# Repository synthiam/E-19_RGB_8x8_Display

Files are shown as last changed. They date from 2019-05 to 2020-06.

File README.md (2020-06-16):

# E-19 RGB 8x8 Display

**Project Status:** Ready to manufacture

If you are new to GitHub and would like to create a derivative of this project, please have a look at GitHub instructions to [fork a repo](https://help.github.com/en/articles/fork-a-repo)

## Description

Out of our passion to solve the issue of time waste in the robot creation process, ARC was born. The ARC software platform reduces the time it takes to get from idea to implementation. Since 2011 we have been listening to the challenges robot builders encounter and continue to provide them with an ever expanding toolbox of solutions. Join us on this journey!

We didn't stop at the software, we also made time saving hardware solutions. This RGB Matrix display reference design is one of them. It has 64 (8x8 matrix) Full color LEDs. Each LED can be individually controlled by EZ-builder to form messages, pictures, games, and more! A unique feature of this display is that it is a smaller form factor (48x48mm) than common RGB matrix dispalys (60x60mm). We want to share these files with you so you can create your own version for your community and customers to enjoy!

**Features:**
- I2C communication
- Adjustable I2C address for chaining multiple displays
- PIC programming header
- 5V tolerant I/O pins
- Address displayed on boot
- ARC skill available
- Small form factor RGB display
- Vibrant Green color, better than majority of matrix displays 
- Voltage requirement: 3.2-3.4VDC (3.3V Typical)
- Current draw: All LEDs off - 6.6mA, All Blue - 86mA, All Green - 106mA, All Red - 154mA, All White - 273mA
- Dimensions: 48(W) x 48(L) x 15.6(H) (mm)
- Weight: 32g

**Major components:** 
- HS-19088BSRND-GG RGB 8x8 LED Matrix
- PIC16F1937 PIC microcontroller (custom firmware provided)

**Manufacturing notes:** 
1. Supplier: programs custom firmware into the PIC16F1937 at their facility before sending to manufacturer
2. Manufacturer: Single side placement and soldering of SMT components
3. Manufacturer: Dual Side soldering of THT components

## Contents

[**Documentation:**](https://github.com/synthiam/E-19_RGB_8x8_Display/tree/master/E-19%20Documentation) Schematic PDF, Datasheet PDF, BOM, Assembly Notes, Test Procedures

[**Hardware:**](https://github.com/synthiam/E-19_RGB_8x8_Display/tree/master/E-19%20Hardware) Altium PCB design File, Altium SCH Design File, Gerbers

[**Firmware:**](https://github.com/synthiam/E-19_RGB_8x8_Display/tree/master/E-19%20Firmware) Code, Compiled Hex

*Altium Libraries are also available <a href="https://github.com/synthiam/Synthiam_Altium_Librairies">here</a>*

## Photos

<p align="left">


</p>

## Roll Out Video

This Roll-out Video includes:

1. Feature set 
2. Hook-up guide 
3. Using ARC Skill
4. Schematic overview
5. Bill of Materials (BOM) overview
6. Custom firmware location
7. Assembly instructions 

Link: https://youtu.be/Iwhcii0WCHs



## ARC Skill

The ARC skill for this reference design is very easy to use! Simply add an animation frame, click on the pixels, choose the color, and repeat! Activate the animations with the click of a mouse button or with code. 

Link: https://synthiam.com/Software/Manual/RGB-8x8-Animator-16173

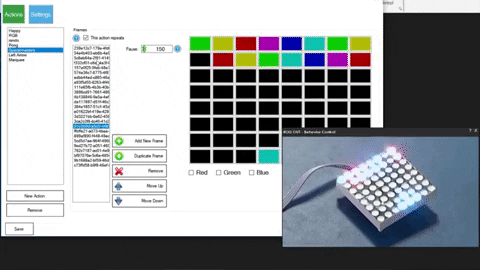
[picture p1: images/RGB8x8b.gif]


## Contact

For profit use of these files requires written consent. Contact partners@synthiam.com. For everyone else, party on!

Synthiam Website: https://synthiam.com

## License

This project is released under the following licenses:

**Hardware:** Creative Commons Plus Attribution-NonCommercial 4.0 International (CC+ BY-NC 4.0)

**Firmware:** Apache 2.0 + “Commons Clause” License Condition v1.0

Please see [LICENSE.md](https://github.com/synthiam/E-19_RGB_8x8_Display/blob/master/LICENSE.md) for license details.



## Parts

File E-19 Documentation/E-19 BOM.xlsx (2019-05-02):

Qty | Description | Manufacturer Part No. | Alternative | Designator | Custom Information | Link
E-19 RGB 8x8 Display
1 | 2 layer, Blue soldermask, White silkscreen, ENIG | RGB 8x8 Display Board |  | PCB
1 | 2 layer, Blue soldermask, White silkscreen, ENIG | EZ-clip Board |  | PCB2
1 | Microchip Microcontroller | PIC16F1937-I/PT |  | U1 | Needs Eyes Firmware programmed onto chip before manufacturing | https://www.digikey.ca/products/en?keywords=PIC16F1937-I%2FPT
1 | 4-pin 2mm pitch JST-PH SMD connector | S4B-PH-SM4-TB(LF)(SN) |  | P2 |  | https://www.digikey.ca/products/en?keywords=%09455-1706-ND
8 | 530mA 30V P-Channel MOSFET SOT23 low gate capacitance (76pF) | DMP31D0U-7 |  | Q1, Q2 |  | http://www.digikey.ca/product-detail/en/S4B-PH-SM4-TB(LF)(SN)/455-1751-1-ND/926848
1 | 0.1uF 16V 0805 Ceramic Capacitor | CL21F104ZBCNNNC | C0805C104K5RAC | C3
10 | 4.7Kohm 0805 Resistor | RR1220P-472-D |  | R2, R3, R4, R5, R6, R7, R8, R9, R10, R11
1 | 40-pin Black Male 0.1” pitch header | FIT0084-B | 00834 | P5, P6 | This header needs to be broken down into 2 x 4-pin | http://www.4uconnector.com/online/SearchPro.asp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
1 | Common Anode 1.9" 8x8 RGB LED display white diffused lens, black foreground | HS-19088BSRND-GG |  | P3, P4 |  | https://www.alibaba.com/product-detail/8x8-RGB-LED-Matrix-Display-48x48x9mm_60031953303.html
2 | 10mm (W) x 10mm (L) x 1mm (H) Doubled sided foam tape |  |  |  | Need to cut to length | http://www.aliexpress.com/item/1mm-thick-10mm-width-3M-Automotive-Acrylic-Foam-Double-Sided-Adhesive-Tape-x-2-Rolls/32495049028.html

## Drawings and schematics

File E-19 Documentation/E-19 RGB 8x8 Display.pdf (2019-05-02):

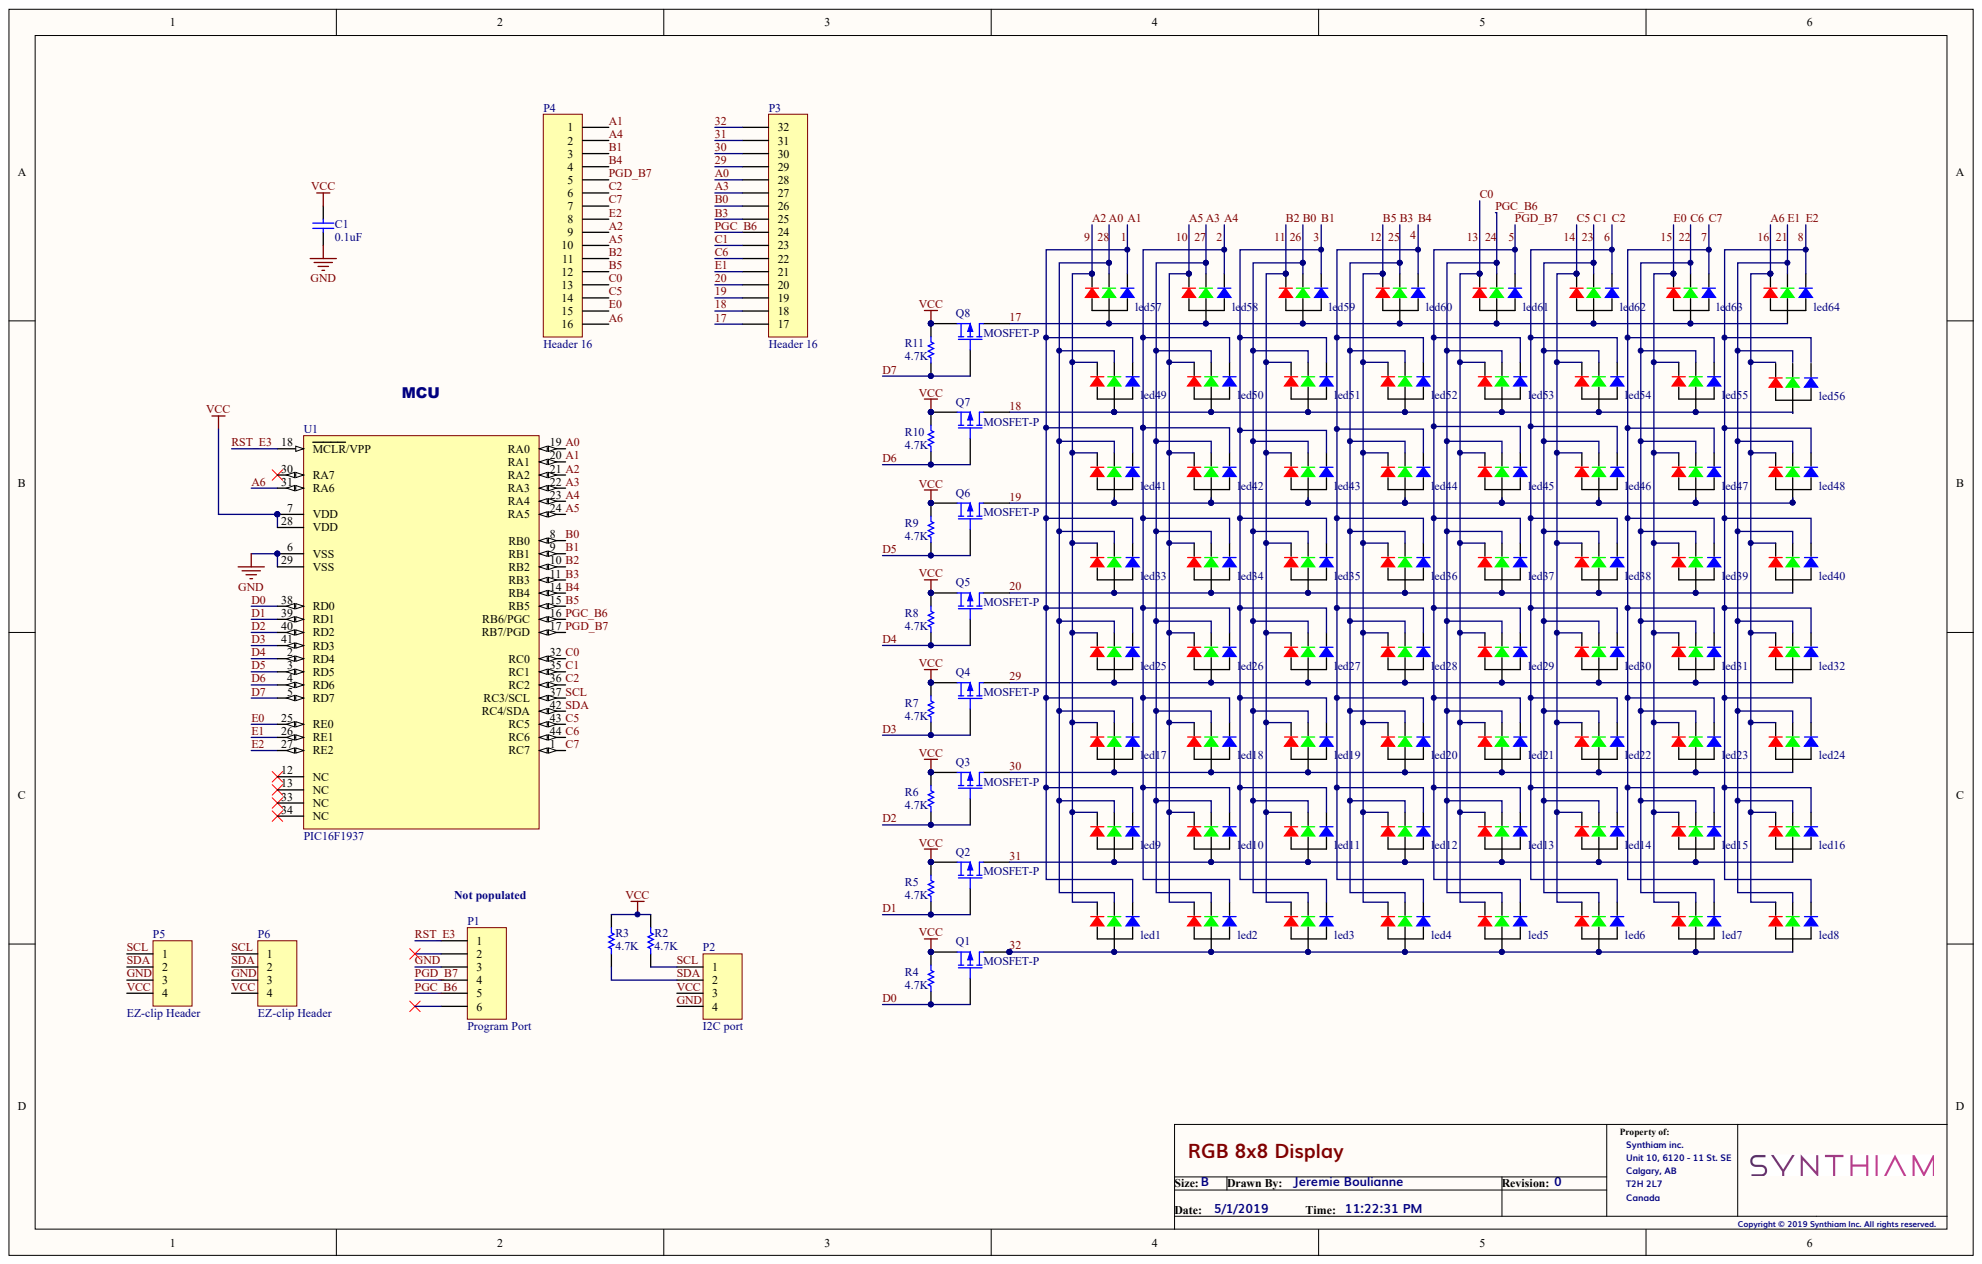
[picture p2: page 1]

RGB 8x8 Display | Property of: Synthiam inc. Unit 10, 6120 - 11 St. SE Calgary, AB T2H 2L7 Canada

B Size: | Jeremie Boulianne Drawn By: | 0 Revision:
5/1/2019 11:22:31 PM Date: Time:

Copyright © 2019 Synthiam Inc. All rights reserved.

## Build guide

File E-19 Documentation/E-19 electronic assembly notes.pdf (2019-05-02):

# Assembly Instructions

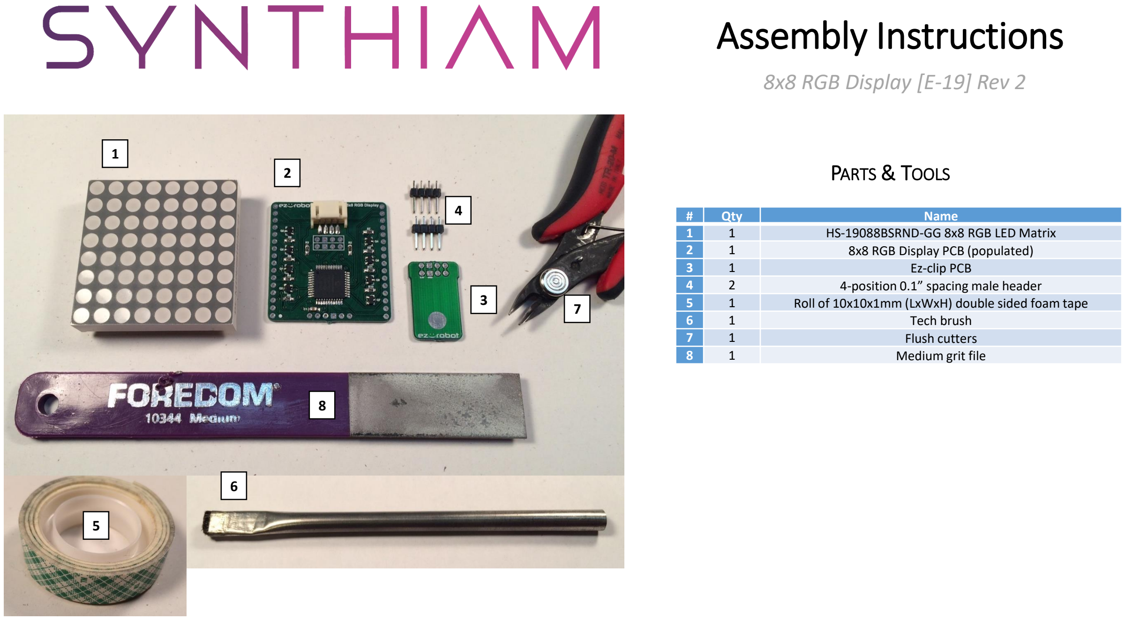
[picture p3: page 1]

# | Qty | Name

1 | 1 | HS-19088BSRND-GG 8x8 RGB LED Matrix
2 | 1 | 8x8 RGB Display PCB (populated)
3 | 1 | Ez-clip PCB
4 | 2 | 4-position 0.1” spacing male header
5 | 1 | Roll of 10x10x1mm (LxWxH) double sided foam tape
6 | 1 | Tech brush
7 | 1 | Flush cutters
8 | 1 | Medium grit file

8x8 RGB Display [E-19] Rev 2

PARTS & TOOLS

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
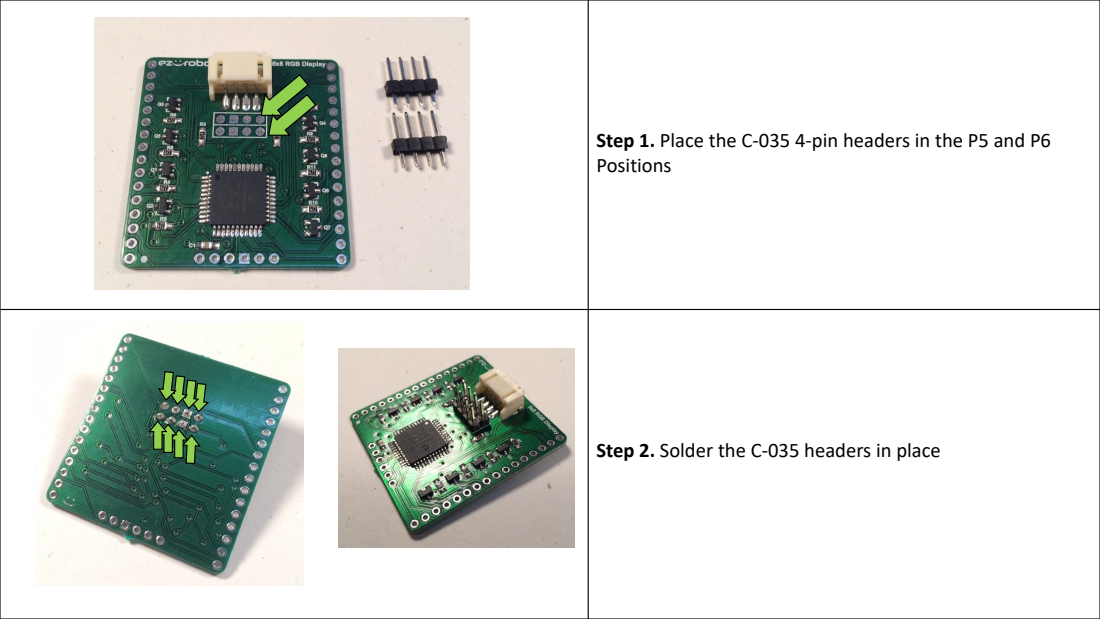
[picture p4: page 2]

Step 1. Place the C-035 4-pin headers in the P5 and P6
Positions

Step 2. Solder the C-035 headers in place

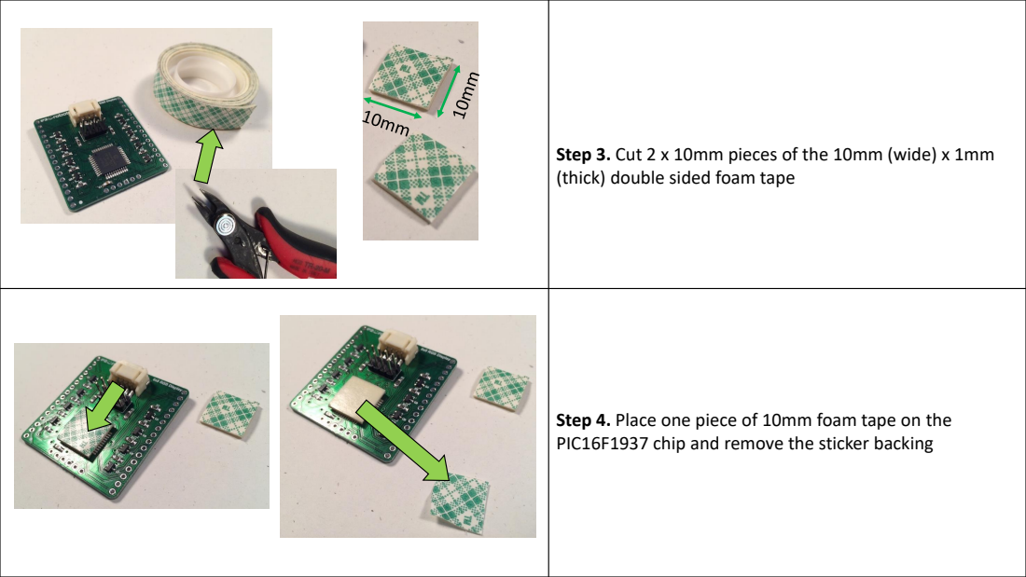
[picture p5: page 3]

Step 3. Cut 2 x 10mm pieces of the 10mm (wide) x 1mm
(thick) double sided foam tape

Step 4. Place one piece of 10mm foam tape on the
PIC16F1937 chip and remove the sticker backing

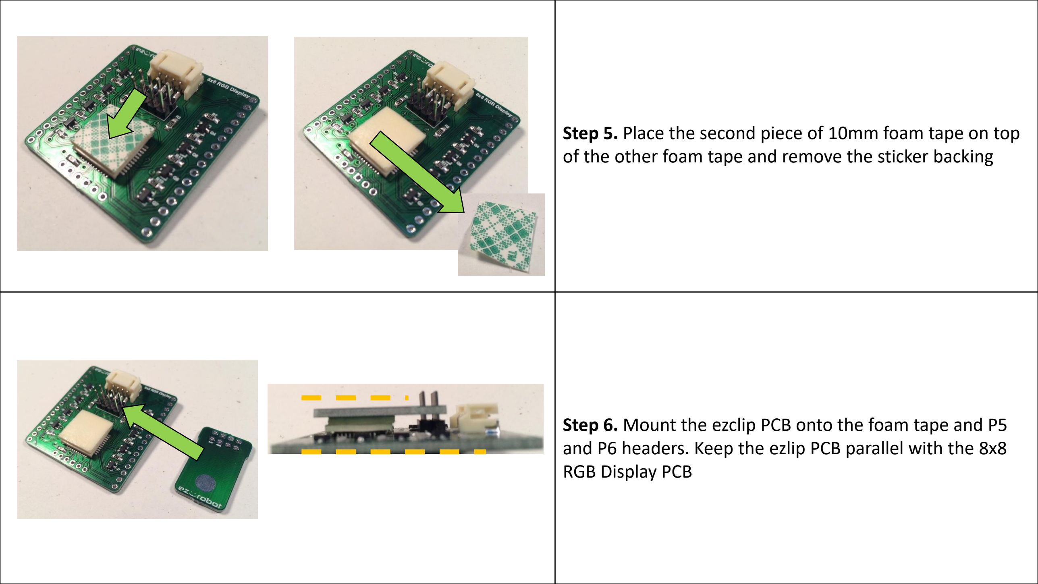
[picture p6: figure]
RGB Display PCB

Step 5. Place the second piece of 10mm foam tape on top of the other foam tape and remove the sticker backing
Step 6. Mount the ezclip PCB onto the foam tape and P5 and P6 headers. Keep the ezlip PCB parallel with the 8x8

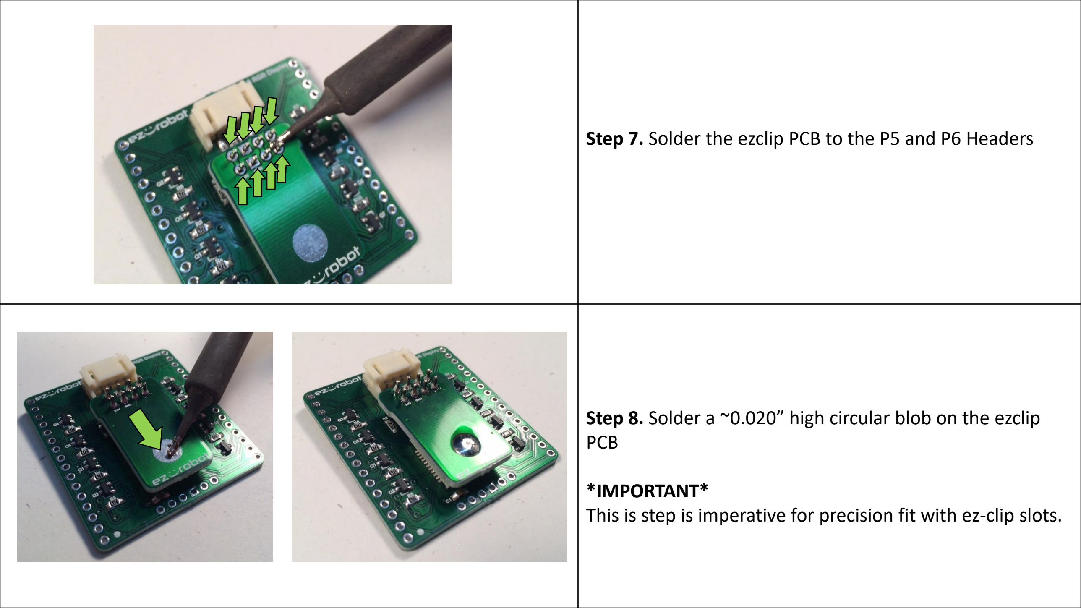
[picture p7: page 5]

Step 7. Solder the ezclip PCB to the P5 and P6 Headers
Step 8. Solder a ~0.020” high circular blob on the ezclip PCB

*IMPORTANT*
This is step is imperative for precision fit with ez-clip slots.

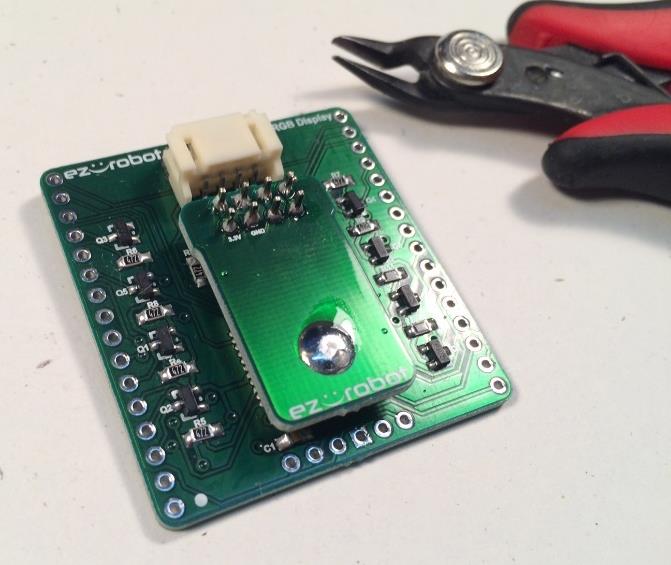
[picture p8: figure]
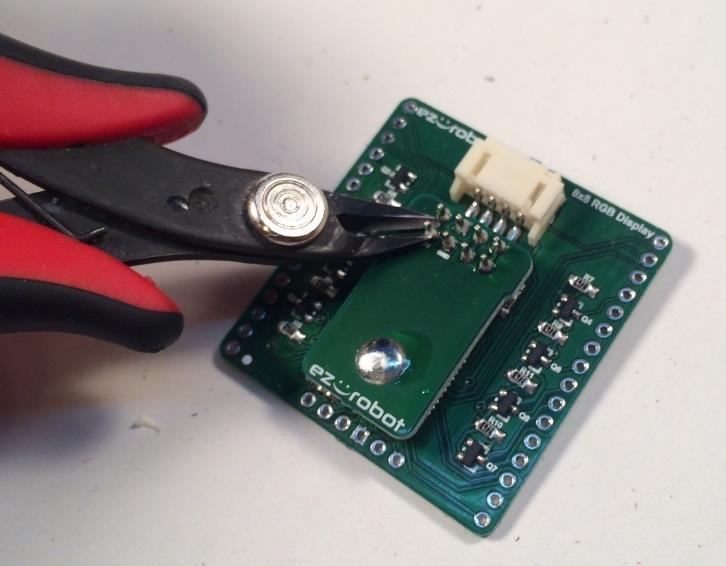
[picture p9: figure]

Step 9. Clip the P5 and P6 header pins as close to the PCB as possible

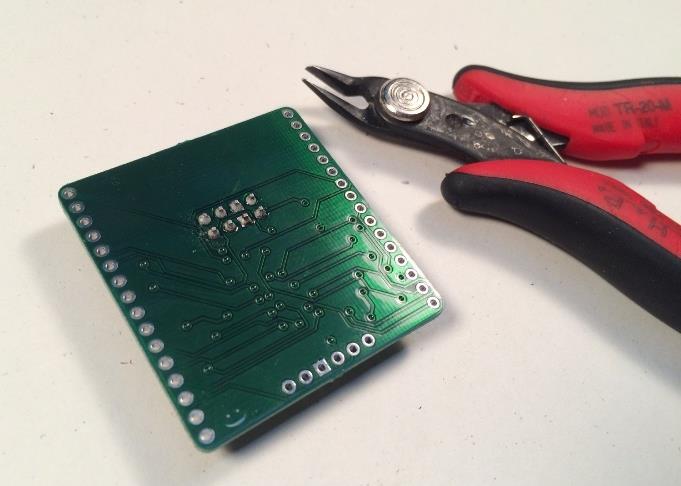
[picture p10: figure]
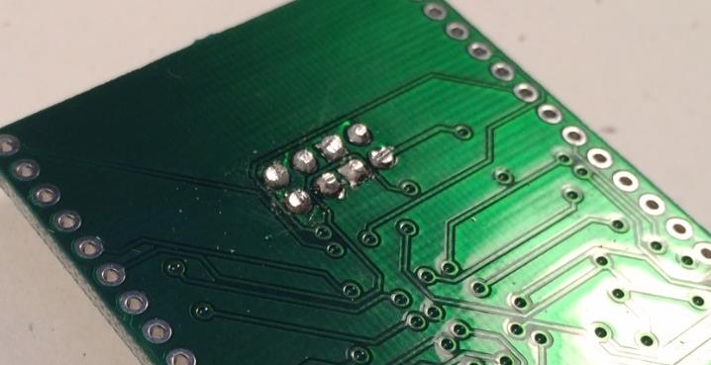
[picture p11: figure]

Step 10. Turn the board upside down and trim the P5 and P6 header pins as close to the PCB as possible too

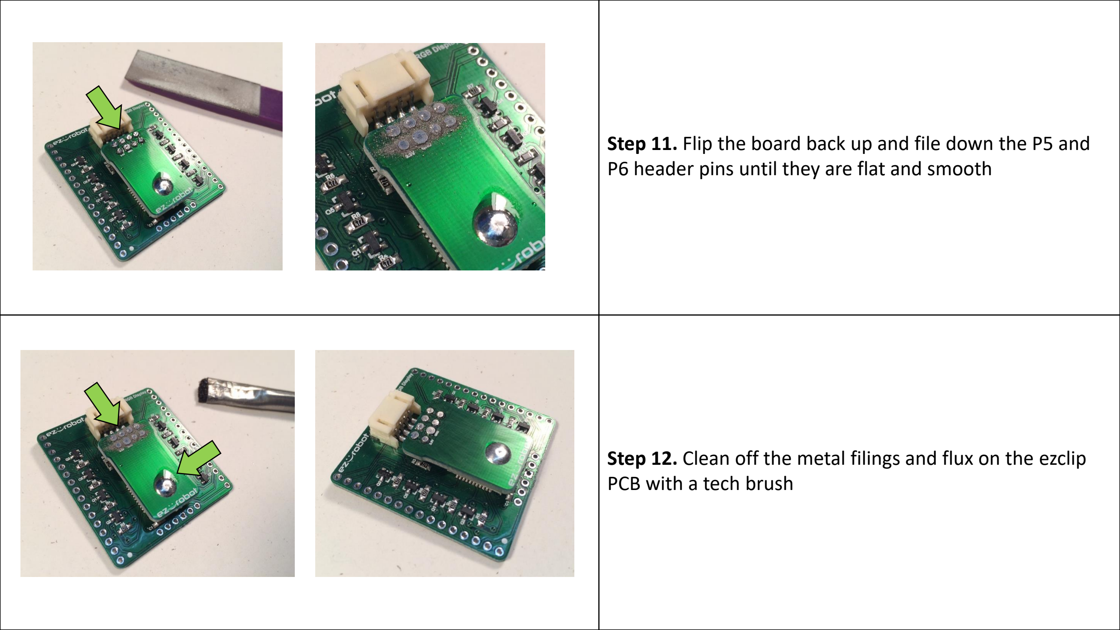
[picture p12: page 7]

Step 11. Flip the board back up and file down the P5 and P6 header pins until they are flat and smooth
Step 12. Clean off the metal filings and flux on the ezclip PCB with a tech brush

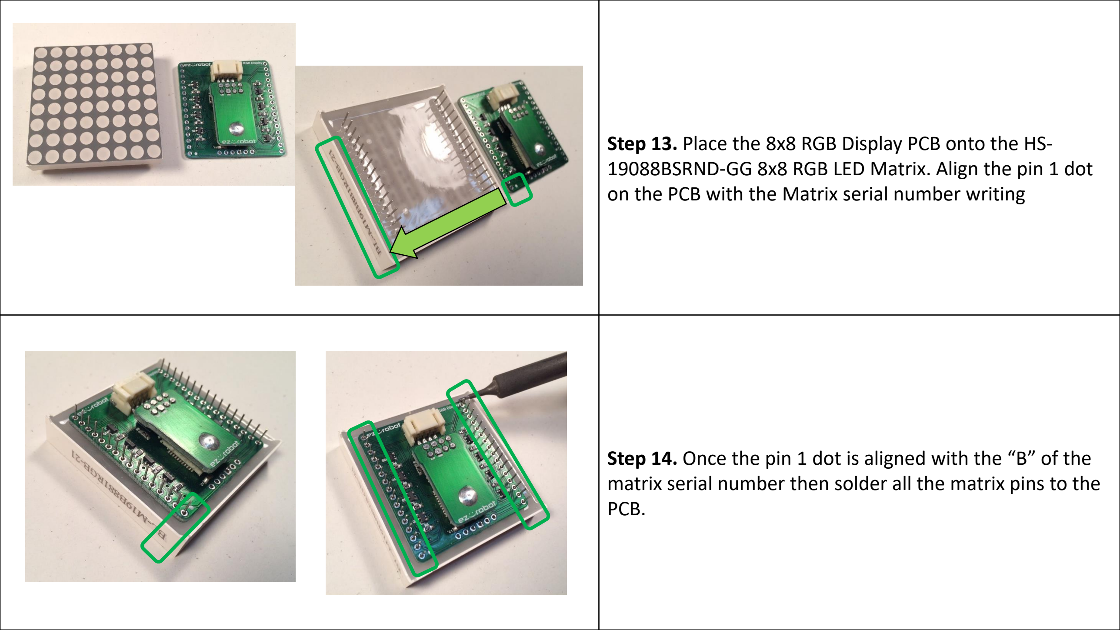
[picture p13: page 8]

Step 13. Place the 8x8 RGB Display PCB onto the HS-19088BSRND-GG 8x8 RGB LED Matrix. Align the pin 1 dot on the PCB with the Matrix serial number writing
Step 14. Once the pin 1 dot is aligned with the “B” of the matrix serial number then solder all the matrix pins to the PCB.

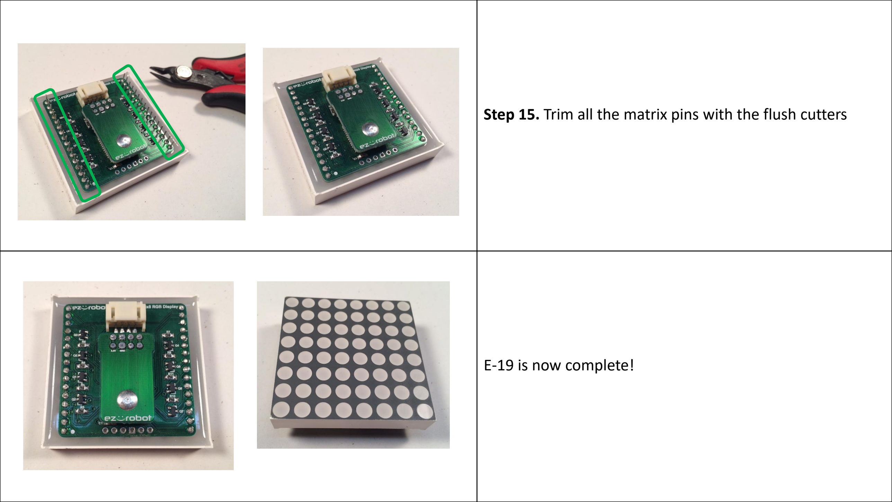
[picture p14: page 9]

Step 15. Trim all the matrix pins with the flush cutters

E-19 is now complete!

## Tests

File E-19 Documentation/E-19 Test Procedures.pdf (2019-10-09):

# Electronic Test Instructions

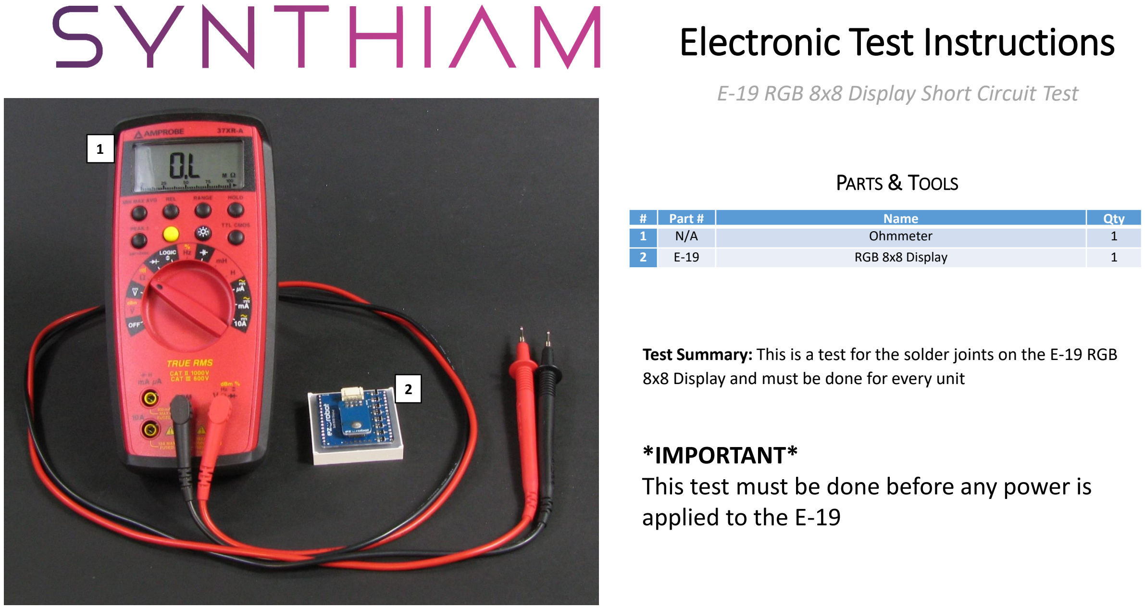
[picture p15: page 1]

# | Part # | Name | Qty

1 | N/A | Ohmmeter | 1
2 | E-19 | RGB 8x8 Display | 1

E-19 RGB 8x8 Display Short Circuit Test

PARTS & TOOLS

Test Summary: This is a test for the solder joints on the E-19 RGB 8x8 Display and must be done for every unit

*IMPORTANT*
This test must be done before any power is applied to the E-19

1

2

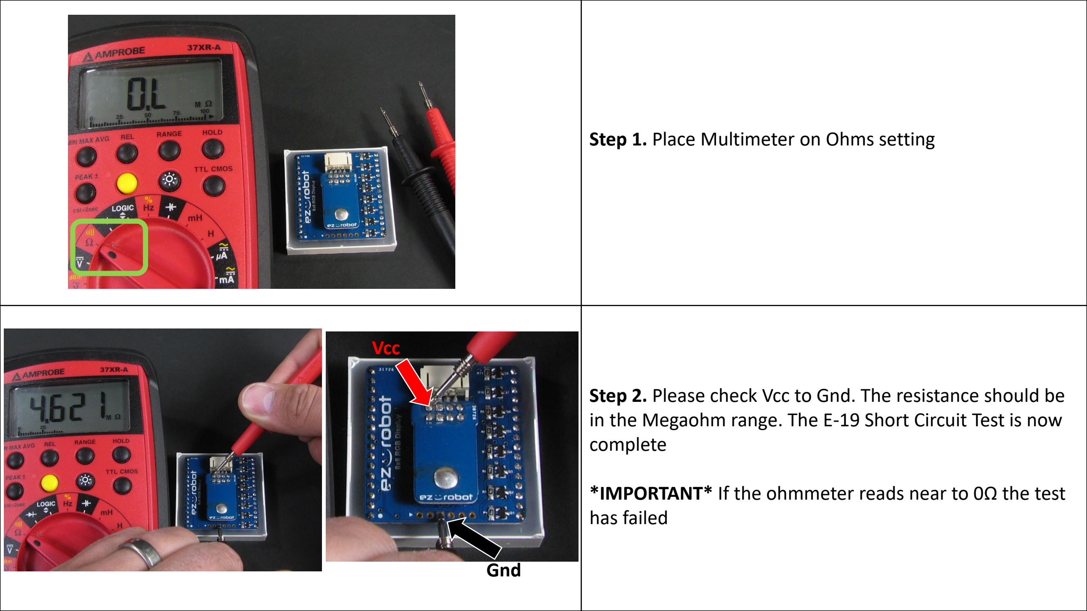
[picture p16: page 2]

Step 1. Place Multimeter on Ohms setting
Step 2. Please check Vcc to Gnd. The resistance should be in the Megaohm range. The E-19 Short Circuit Test is now complete

*IMPORTANT* If the ohmmeter reads near to 0Ω the test has failed

Vcc

Gnd

# Electronic Test Instructions

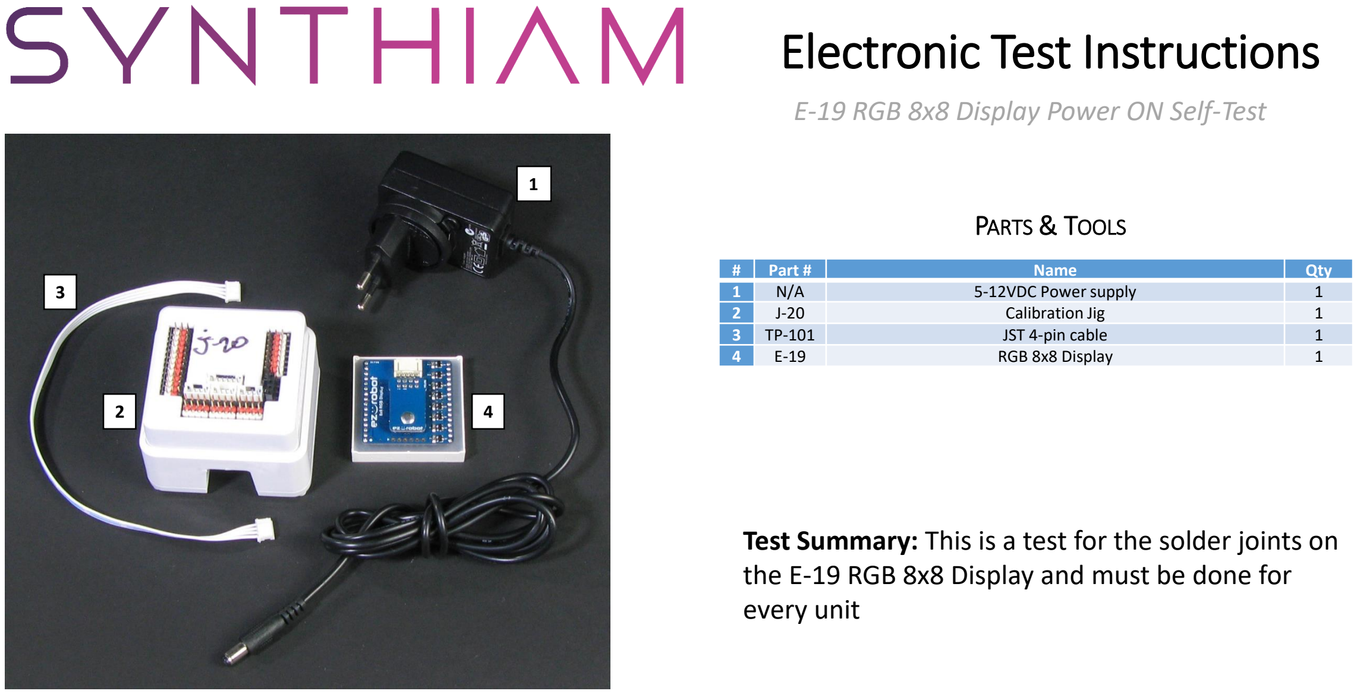
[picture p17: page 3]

# | Part # | Name | Qty

1 | N/A | 5-12VDC Power supply | 1
2 | J-20 | Calibration Jig | 1
3 | TP-101 | JST 4-pin cable | 1
4 | E-19 | RGB 8x8 Display | 1

E-19 RGB 8x8 Display Power ON Self-Test

PARTS & TOOLS

1

2

3

4

Test Summary: This is a test for the solder joints on the E-19 RGB 8x8 Display and must be done for every unit

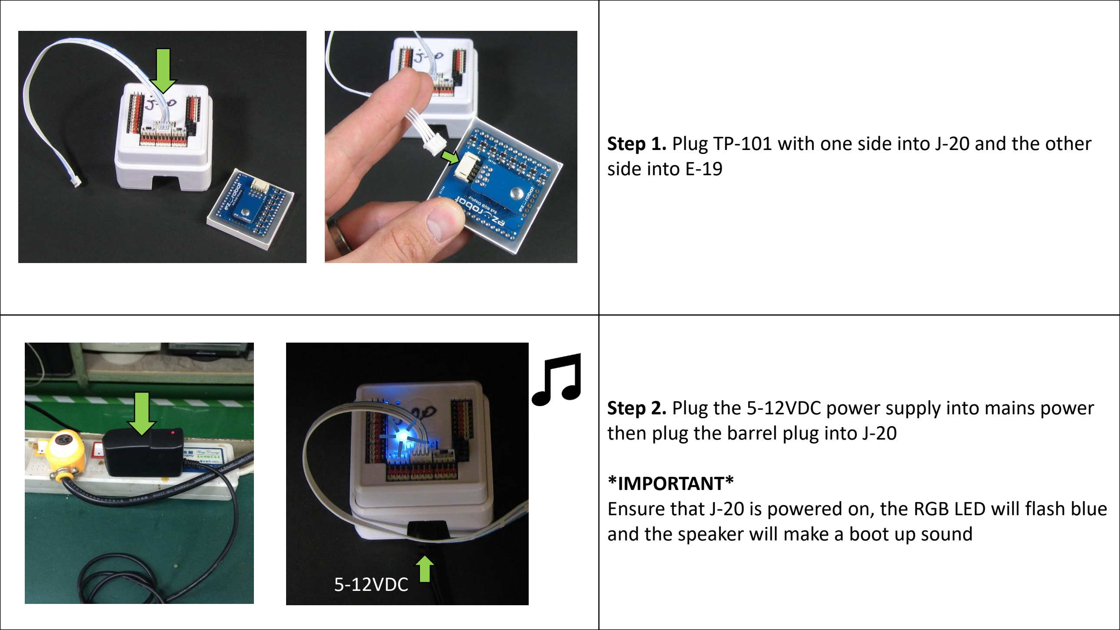
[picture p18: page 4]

Step 1. Plug TP-101 with one side into J-20 and the other side into E-19
Step 2. Plug the 5-12VDC power supply into mains power then plug the barrel plug into J-20

*IMPORTANT*
Ensure that J-20 is powered on, the RGB LED will flash blue and the speaker will make a boot up sound

5-12VDC

5-12VDC

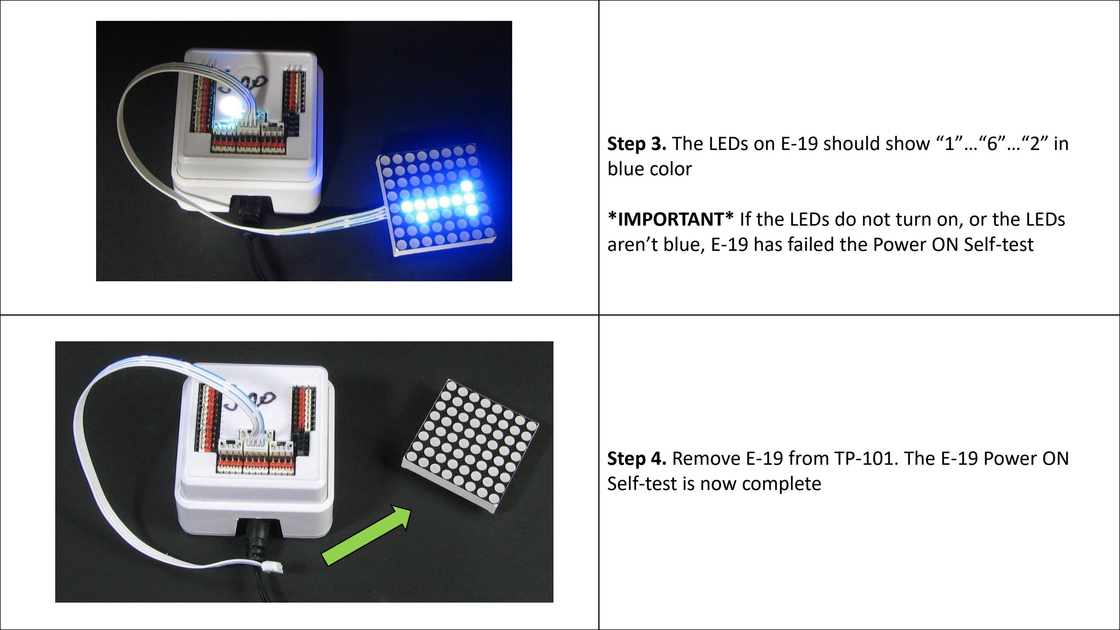
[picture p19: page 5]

Step 3. The LEDs on E-19 should show “1”…“6”…“2” in blue color

*IMPORTANT* If the LEDs do not turn on, or the LEDs aren’t blue, E-19 has failed the Power ON Self-test

Step 4. Remove E-19 from TP-101. The E-19 Power ON Self-test is now complete

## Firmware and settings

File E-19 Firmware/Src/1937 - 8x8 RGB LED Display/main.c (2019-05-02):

#include "main.h"

volatile unsigned bool redA[8][8];
volatile unsigned bool greenA[8][8];
volatile unsigned bool blueA[8][8];

unsigned int8 _address;
volatile char          _digits[3] = {0, 0, 0};

volatile unsigned int16 _cnt = 0;

#inline
void clearDisplay() {

  for (int x = 0; x < 8; x++)
    for (int y = 0; y < 8; y++) {
    
      redA[x][y] = false;
      greenA[x][y] = false;
      blueA[x][y] = false;
    }
}

#inline
void clearDisplayColor(bool r, bool g, bool b) {

  for (int x = 0; x < 8; x++)
    for (int y = 0; y < 8; y++) {
    
      redA[x][y] = r;
      greenA[x][y] = g;
      blueA[x][y] = b;
    }
}

void SetLEDPosition(unsigned int8 x, unsigned int8 y, bool red, bool green, bool blue) {
 
  redA[x][7 - y] = red;
  greenA[x][7 - y] = green;
  blueA[x][7 - y] = blue;
}

void loop1() {

  int x = 0;
  
  while (true) {
  
    output_low(Trans[x]);
  
    if (greenA[x][0])
      output_low(gPin[0]);
  
    if (greenA[x][1])
      output_low(gPin[1]);
  
    if (greenA[x][2])
      output_low(gPin[2]);
  
    if (greenA[x][3])
      output_low(gPin[3]);
  
    if (greenA[x][4])
      output_low(gPin[4]);
  
    if (greenA[x][5])
      output_low(gPin[5]);
  
    if (greenA[x][6])
      output_low(gPin[6]);
  
    if (greenA[x][7])
      output_low(gPin[7]);
  
    // blue
    if (blueA[x][0])
      output_low(bPin[0]);
  
    if (blueA[x][1])
      output_low(bPin[1]);
  
    if (blueA[x][2])
      output_low(bPin[2]);
  
    if (blueA[x][3])
      output_low(bPin[3]);
  
    if (blueA[x][4])
      output_low(bPin[4]);
  
    if (blueA[x][5])
      output_low(bPin[5]);
  
    if (blueA[x][6])
      output_low(bPin[6]);
  
    if (blueA[x][7])
      output_low(bPin[7]);
  
    // red
    if (redA[x][0])
      output_low(rPin[0]);
  
    if (redA[x][1])
      output_low(rPin[1]);
  
    if (redA[x][2])
      output_low(rPin[2]);
  
    if (redA[x][3])
      output_low(rPin[3]);
  
    if (redA[x][4])
      output_low(rPin[4]);
  
    if (redA[x][5])
      output_low(rPin[5]);
  
    if (redA[x][6])
      output_low(rPin[6]);
  
    if (redA[x][7])
      output_low(rPin[7]);
  
    delay_us(ON_DELAY_US);
    
    output_high(rPin[0]);        
    output_high(rPin[1]);        
    output_high(rPin[2]);        
    output_high(rPin[3]);        
    output_high(rPin[4]);        
    output_high(rPin[5]);        
    output_high(rPin[6]);        
    output_high(rPin[7]);        

    output_high(bPin[0]);        
    output_high(bPin[1]);        
    output_high(bPin[2]);        
    output_high(bPin[3]);        
    output_high(bPin[4]);        
    output_high(bPin[5]);        
    output_high(bPin[6]);        
    output_high(bPin[7]);        

    output_high(gPin[0]);        
    output_high(gPin[1]);        
    output_high(gPin[2]);        
    output_high(gPin[3]);        
    output_high(gPin[4]);        
    output_high(gPin[5]);        
    output_high(gPin[6]);        
    output_high(gPin[7]);        

    output_high(Trans[x]);      
    
    x++;
    
    if (x == 8)
      x = 0;
  }
}

volatile unsigned int8 _mode = 0; // 1 = change led by address, 2 = change i2c address, 3 = clear display
volatile unsigned int8 _changeAddress;
volatile unsigned int8 _tmp;
volatile unsigned int8 _state;

#INT_SSP
void ssp_interupt() {

  _state = i2c_isr_state();
    
  if (_state == 0) {      
  
    // this device address matched for the master to write to us
    // we read but it's our own address anyway
    _tmp = i2c_read();    
    _mode = 0;
    
  } else if (_state >= 1 && _state <= 127) {

    // now we receive all the data that the master is writing to us
    // this is the "memory" that the client is writing. All sequential data after this byte is "data"
    _tmp = i2c_read();

    if (_state == 1) {
      
      // let's get the address they are writing to
      
      if (_tmp == 200) {

        // the next byte of data is going to be the new i2c address to store in eeprom
        _mode = 2;
      } else if (_tmp >= 240 && _tmp <= 247) {
        
        _mode = 3;
        
        clearDisplayColor(CHECK_BIT(_tmp, 2), CHECK_BIT(_tmp, 1), CHECK_BIT(_tmp, 0));
      } else {

        // all next bytes of data are led colors
        _mode = 1;

        // get the address that we will begin writing to for all consecutive byte
        _changeAddress = _tmp;
      }
    } else {
    
      if (_mode == 1) {
  
        // now that we know the starting memory address from the first byte send, we will write the data from this transmission to that address and then increment
  
        unsigned int8 y = _changeAddress / 8;
        unsigned int8 x = _changeAddress % 8;
  
        SetLEDPosition(x, y, CHECK_BIT(_tmp, 2), CHECK_BIT(_tmp, 1), CHECK_BIT(_tmp, 0));
        
        // increment the address (which is actually the next led) incase there is an additional transmission
        _changeAddress++;
      } else if (_mode == 2) {
  
        // if the tmp data is within an acceptable i2c address range, write it to eeprom and we will use it for next power-up
        if (_tmp >= 130 && _tmp <= 180) {
        
          write_eeprom(0, _tmp);

          clearDisplay();
                    
          // O
          SetLEDPosition(1, 2, false, false, true);
          SetLEDPosition(2, 2, false, false, true);
          SetLEDPosition(0, 3, false, false, true);
          SetLEDPosition(3, 3, false, false, true);
          SetLEDPosition(0, 4, false, false, true);
          SetLEDPosition(3, 4, false, false, true);
          SetLEDPosition(1, 5, false, false, true);
          SetLEDPosition(2, 5, false, false, true);

          // K
          SetLEDPosition(5, 2, false, false, true);
          SetLEDPosition(5, 3, false, false, true);
          SetLEDPosition(5, 4, false, false, true);
          SetLEDPosition(5, 5, false, false, true);
          SetLEDPosition(6, 3, false, false, true);
          SetLEDPosition(6, 4, false, false, true);
          SetLEDPosition(7, 2, false, false, true);
          SetLEDPosition(7, 5, false, false, true);          
        }
      }
    }
  }
}

void displayDigit(unsigned int digit) {
  
  clearDisplay();
  
  switch (digit) {
    case 0:
      SetLEDPosition(2, 1, false, false, true);
      SetLEDPosition(3, 1, false, false, true);
      SetLEDPosition(4, 1, false, false, true);
      SetLEDPosition(5, 1, false, false, true);      
      
      SetLEDPosition(2, 6, false, false, true);
      SetLEDPosition(3, 6, false, false, true);
      SetLEDPosition(4, 6, false, false, true);
      SetLEDPosition(5, 6, false, false, true);

      SetLEDPosition(1, 2, false, false, true);
      SetLEDPosition(1, 3, false, false, true);
      SetLEDPosition(1, 4, false, false, true);
      SetLEDPosition(1, 5, false, false, true);

      SetLEDPosition(6, 2, false, false, true);
      SetLEDPosition(6, 3, false, false, true);
      SetLEDPosition(6, 4, false, false, true);
      SetLEDPosition(6, 5, false, false, true);
      break;   
    case 1:
      SetLEDPosition(3, 1, false, false, true);
      SetLEDPosition(3, 2, false, false, true);
      SetLEDPosition(3, 3, false, false, true);
      SetLEDPosition(3, 4, false, false, true);
      SetLEDPosition(3, 5, false, false, true);
      SetLEDPosition(3, 6, false, false, true);
    
      SetLEDPosition(2, 2, false, false, true);    

      SetLEDPosition(2, 6, false, false, true);    
      SetLEDPosition(4, 6, false, false, true);    
      break;
    case 2:
      SetLEDPosition(2, 1, false, false, true);
      SetLEDPosition(3, 1, false, false, true);
      SetLEDPosition(4, 1, false, false, true);
      SetLEDPosition(5, 1, false, false, true);
      

      SetLEDPosition(1, 2, false, false, true);
      SetLEDPosition(6, 2, false, false, true);

      SetLEDPosition(6, 3, false, false, true);

      SetLEDPosition(2, 4, false, false, true);
      SetLEDPosition(3, 4, false, false, true);
      SetLEDPosition(4, 4, false, false, true);
      SetLEDPosition(5, 4, false, false, true);
    
      SetLEDPosition(1, 5, false, false, true);
    
      SetLEDPosition(1, 6, false, false, true);
      SetLEDPosition(2, 6, false, false, true);
      SetLEDPosition(3, 6, false, false, true);
      SetLEDPosition(4, 6, false, false, true);
      SetLEDPosition(5, 6, false, false, true);
      SetLEDPosition(6, 6, false, false, true);
      break;
    case 3:
      SetLEDPosition(2, 1, false, false, true);
      SetLEDPosition(3, 1, false, false, true);
      SetLEDPosition(4, 1, false, false, true);
      SetLEDPosition(5, 1, false, false, true);

      SetLEDPosition(6, 2, false, false, true);
      
      SetLEDPosition(5, 3, false, false, true);
      
      SetLEDPosition(4, 4, false, false, true);
      SetLEDPosition(5, 4, false, false, true);

      SetLEDPosition(6, 5, false, false, true);

      SetLEDPosition(2, 6, false, false, true);
      SetLEDPosition(3, 6, false, false, true);
      SetLEDPosition(4, 6, false, false, true);
      SetLEDPosition(5, 6, false, false, true);
      break;      
    case 4:
      SetLEDPosition(2, 1, false, false, true);
      SetLEDPosition(2, 2, false, false, true);
      SetLEDPosition(2, 3, false, false, true);
      SetLEDPosition(2, 4, false, false, true);

      SetLEDPosition(5, 1, false, false, true);
      SetLEDPosition(5, 2, false, false, true);
      SetLEDPosition(5, 3, false, false, true);
      SetLEDPosition(5, 4, false, false, true);
      SetLEDPosition(5, 5, false, false, true);
      SetLEDPosition(5, 6, false, false, true);
    
      SetLEDPosition(3, 4, false, false, true);
      SetLEDPosition(4, 4, false, false, true);
      SetLEDPosition(6, 4, false, false, true);
    
      SetLEDPosition(5, 5, false, false, true);
      SetLEDPosition(5, 6, false, false, true);
      break;
    case 5:
      SetLEDPosition(1, 1, false, false, true);
      SetLEDPosition(2, 1, false, false, true);
      SetLEDPosition(3, 1, false, false, true);
      SetLEDPosition(4, 1, false, false, true);
      SetLEDPosition(5, 1, false, false, true);
     
      SetLEDPosition(1, 2, false, false, true);
     
      SetLEDPosition(1, 3, false, false, true);
      SetLEDPosition(2, 3, false, false, true);
      SetLEDPosition(3, 3, false, false, true);
      SetLEDPosition(4, 3, false, false, true);

      SetLEDPosition(5, 4, false, false, true);
      
      SetLEDPosition(5, 5, false, false, true);   
      SetLEDPosition(1, 5, false, false, true);

      SetLEDPosition(2, 6, false, false, true);   
      SetLEDPosition(3, 6, false, false, true);   
      SetLEDPosition(4, 6, false, false, true);      
      break;
    case 6:
      SetLEDPosition(2, 1, false, false, true);
      SetLEDPosition(3, 1, false, false, true);
      SetLEDPosition(4, 1, false, false, true);
      
      SetLEDPosition(1, 2, false, false, true);
      
      SetLEDPosition(1, 3, false, false, true);

      SetLEDPosition(1, 4, false, false, true);
      SetLEDPosition(2, 4, false, false, true);
      SetLEDPosition(3, 4, false, false, true);
      SetLEDPosition(4, 4, false, false, true);
      SetLEDPosition(5, 4, false, false, true);
     
      SetLEDPosition(1, 5, false, false, true);
      SetLEDPosition(5, 5, false, false, true);
     
      SetLEDPosition(2, 6, false, false, true);
      SetLEDPosition(3, 6, false, false, true);
      SetLEDPosition(4, 6, false, false, true);
      break;
    case 7:
      SetLEDPosition(1, 1, false, false, true);
      SetLEDPosition(2, 1, false, false, true);
      SetLEDPosition(3, 1, false, false, true);
      SetLEDPosition(4, 1, false, false, true);
      SetLEDPosition(5, 1, false, false, true);

      SetLEDPosition(5, 2, false, false, true);
    
      SetLEDPosition(4, 3, false, false, true);
    
      SetLEDPosition(3, 4, false, false, true);
      SetLEDPosition(3, 5, false, false, true);
      SetLEDPosition(3, 6, false, false, true);
      break;
    case 8:
      SetLEDPosition(2, 1, false, false, true);
      SetLEDPosition(3, 1, false, false, true);
      SetLEDPosition(4, 1, false, false, true);
      
      SetLEDPosition(1, 2, false, false, true);
      SetLEDPosition(5, 2, false, false, true);
    
      SetLEDPosition(2, 3, false, false, true);
      SetLEDPosition(3, 3, false, false, true);
      SetLEDPosition(4, 3, false, false, true);
    
      SetLEDPosition(1, 4, false, false, true);
      SetLEDPosition(5, 4, false, false, true);
    
      SetLEDPosition(1, 5, false, false, true);
      SetLEDPosition(5, 5, false, false, true);

      SetLEDPosition(2, 6, false, false, true);
      SetLEDPosition(3, 6, false, false, true);
      SetLEDPosition(4, 6, false, false, true);
      break;
    case 9:
      SetLEDPosition(2, 1, false, false, true);
      SetLEDPosition(3, 1, false, false, true);
      SetLEDPosition(4, 1, false, false, true);
      
      SetLEDPosition(1, 2, false, false, true);
      SetLEDPosition(5, 2, false, false, true);

      SetLEDPosition(1, 3, false, false, true);
      SetLEDPosition(5, 3, false, false, true);
     
      SetLEDPosition(2, 4, false, false, true);
      SetLEDPosition(3, 4, false, false, true);
      SetLEDPosition(4, 4, false, false, true);
      SetLEDPosition(5, 4, false, false, true);
     
      SetLEDPosition(5, 5, false, false, true);
      SetLEDPosition(5, 6, false, false, true);     
      break;
    }
}

#INT_TIMER1
void isr_tmr1() {

  if (_cnt == 0) 
    displayDigit(_digits[2]);
  else if (_cnt == 100)
    clearDisplay();
  else if (_cnt == 150)
    displayDigit(_digits[1]);
  else if (_cnt == 250)
    clearDisplay();
  else if (_cnt == 300) 
    displayDigit(_digits[0]);   
  else if (_cnt == 400) {

    clearDisplay();
  
    disable_interrupts(INT_TIMER1);
    
    setup_timer_1(T1_DISABLED);
  }
  
  _cnt++;
}

void main() {

  clearDisplay();

  // ----------------------------------------------------------------------------------------------
  
  _address = read_eeprom(0);

  if (_address >= 130 && _address <= 180)
    i2c_slaveaddr(_address);
  else
    _address = 0xa2;
    
  int digitsSize = 0;
  
  do {                 

    _digits[digitsSize++] = _address % 10;   /* get next digit */
  } while ((_address /= 10) > 0);   /* delete it */

  // ----------------------------------------------------------------------------------------------

  for (int t = 0; t < 8; t++) {
  
    output_drive(Trans[t]);
    output_high(Trans[t]);

    output_drive(rPin[t]);
    output_high(rPin[t]);

    output_drive(gPin[t]);
    output_high(gPin[t]);

    output_drive(bPin[t]);
    output_high(bPin[t]);
  }

  // ----------------------------------------------------------------------------------------------

  delay_ms(1000);

  // ----------------------------------------------------------------------------------------------

  setup_adc_ports(NO_ANALOGS);
  setup_vref(false);
  setup_comparator(NC_NC_NC_NC);

  setup_timer_1(T1_INTERNAL|T1_DIV_BY_1);

  enable_interrupts(INT_SSP);
  enable_interrupts(INT_TIMER1);
  enable_interrupts(GLOBAL);

  // ----------------------------------------------------------------------------------------------
         
  loop1();
}
